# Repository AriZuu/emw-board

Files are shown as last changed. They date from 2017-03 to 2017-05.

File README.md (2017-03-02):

EMW3165 sensor board
====================

Kicad stuff for EMW3165 based sensor board v2. This small
board has:

- EMW3165 module
- Connector for 1-wire sensors
- SWD connector for programming
- Two alternative power supplies (solder only one):
  - MCP1640 step-up converter, provides 3.3V from 2 AA batteries
  - MAX604 LDO regulator, provides 3.3V from 3 AAA batteries or from console FTDI

I have written two firmware alternatives for board. First 
is [emw-meter][1], which displays temperatures and house power usage. 
Second is [emw-sensor][2], which uses 1-wire devices to measure temperature
and send it to MQTT server.

This is Open Source Hardware, licensed under [CC-BY 4.0][3].
There are [some notes about the board][4] in my blog.

[1]: https://github.com/AriZuu/emw-meter
[2]: https://github.com/AriZuu/emw-sensor
[3]: https://creativecommons.org/licenses/by/4.0/
[4]: http://stonepile.fi/1-wire-wifi-sensor/

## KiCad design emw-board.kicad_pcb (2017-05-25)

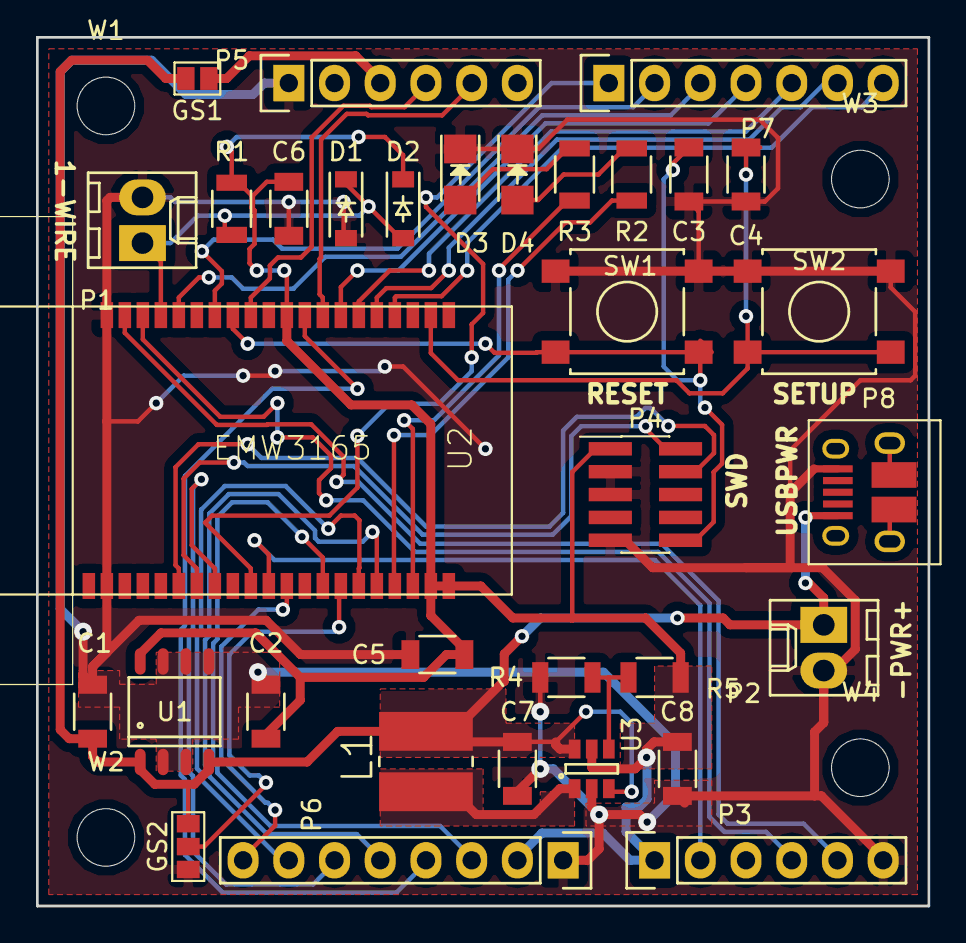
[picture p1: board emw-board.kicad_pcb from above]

Board: 2 copper layers, 49.5 x 48.3 mm, 37 parts (0 on the bottom side), 34 nets.

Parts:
C1, C2: 10uF; C_1206
C3, C4, C5, C6: 100nF; C_1206
C7: 4.7u; C_1206
C8: 10u; C_1206
D1, D2: 1N4148; SOD-123
D3, D4: LED; LED_1206
GS1: GS2
GS2: GS3
L1: SD25-4R7-R; INDM5252X250N
P1: 1WIRE; Molex_KK-6410-02_02x2.54mm_Straight
P2: BATT; Molex_KK-6410-02_02x2.54mm_Straight
P3: CONN_01X06; Pin_Header_Straight_1x06
P4: SWDN; swd_connector_2x05_Pitch1.27mm_SMD
P5: CONS; Pin_Header_Straight_1x06
P6: OLED; Pin_Header_Straight_1x08
P7: CONN_01X07; Pin_Header_Straight_1x07
P8: USB_OTG; USB_Micro-B_10103594-0001LF
R1: 4.7K; R_1206
R2, R3: 270; R_1206
R4: 562K; R_1206
R5: 976K; R_1206
SW1, SW2: B3S-1000; SW_SPST_B3S-1000
U1: MAX604CSA; SO-8
U2: EMW3165
U3: MCP1640; SOT-23-6
W1, W2, W3, W4: TEST_1P; MountingHole_3.2mm_M3

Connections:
+3V3: C2.1, C5.1, C6.1, C8.1, D2.1, P3.1, P4.1, P6.2, R1.1, R5.1, U1.8, U2.10, U2.39, U2.40, U3.5
+BATT: C1.1, C7.1, GS1.2, GS2.1, L1.2, P2.1, P8.1, U1.1, U1.4, U3.3, U3.6
CONS_RX: P5.4, U2.12
CONS_TX: P5.5, U2.8
GND: C1.2, C2.2, C3.2, C4.2, C5.2, C6.2, C7.2, C8.2, D1.2, D3.1, D4.1, GS2.3, P1.2, P2.2, P3.6, P4.3, P4.5, P4.9, P5.1, P6.1, P8.5, R4.2, SW1.1, SW2.1, U1.2, U1.3, U1.5, U1.6, U1.7, U2.20, U2.21, U3.2
unnamed: C3.1, P4.10, SW1.2, U2.13
unnamed: D1.1, D2.2, P1.1, R1.2, U2.17
unnamed: D3.2, R3.1
unnamed: D4.2, R2.1
unnamed: GS1.1, P5.3
unnamed: GS2.2, U2.34
unnamed: L1.1, U3.1
unnamed: P4.2, U2.26
unnamed: P4.4, U2.25
unnamed: R2.2, U2.37
unnamed: R3.2, U2.38
unnamed: R4.1, R5.2, U3.4
OLED_CS: P6.8, U2.31
OLED_DC: P6.6, U2.27
OLED_RST: P6.5, U2.36
PA0: P7.2, U2.14
PA10: P7.1, U2.29
PB6: P3.2, U2.30
PB9: P3.4, U2.18
PB12: P3.5, U2.19
PC13: P7.3, U2.16
SETUP: C4.1, SW2.2, U2.2
SPI1_CLK: P7.5, U2.6
SPI1_CS: P7.6, U2.5
SPI1_MISO: P7.4, U2.7
SPI1_MOSI: P7.7, U2.4
SPI4_CLK: P6.3, U2.33
SPI4_MISO: P6.7, U2.35
SPI4_MOSI: P6.4, U2.9

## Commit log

2016-08-07 Initial commit.
    [emw-board.kicad_pcb, emw-board.sch]
2017-02-24 Fix ERC errors.
    [emw-board.sch]
2017-02-25 ADC connection to VBAT. Replace SWD connector with smaller one.
    [emw-board.sch]
2017-02-25 Reposition buttons. New SWD connector. Reposition power connector.
    [emw-board.kicad_pcb]
2017-02-26 Add OSH logo.
    [emw-board.kicad_pcb]
2017-02-26 Add copper pours.
    [emw-board.kicad_pcb]
2017-02-26 Regenerate copper pours.
    [emw-board.kicad_pcb]
2017-03-01 Move power and 1-wire connector so that right-angled type can also be used.
    [emw-board.kicad_pcb]
2017-05-20 Rotate 1-wire connector.
    [emw-board.kicad_pcb]
2017-05-20 Fix swd connector placing.
    [emw-board.kicad_pcb, emw-board.sch]
2017-05-21 Add BOM info.
    [emw-board.kicad_pcb, emw-board.sch]
2017-05-21 Cleanup some tracks.
    [emw-board.kicad_pcb]
2017-05-21 Remove old silkscreen text for unconnected pin.
    [emw-board.kicad_pcb]
2017-05-23 Add solder jumpers for selecting power from ftdi console and batter level measurement enable/disable.
    [emw-board.kicad_pcb, emw-board.sch]
2017-05-25 Add micro-usb connector (for power only).
    [emw-board.kicad_pcb, emw-board.sch]
2017-05-25 Upgrade to kicad 4.0.6.
    [emw-board.kicad_pcb, emw-board.sch]
